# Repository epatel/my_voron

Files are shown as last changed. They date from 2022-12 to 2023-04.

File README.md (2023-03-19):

# My Vorons

## Voron 2.4r2

```
Size: 300x300
Hotend: E3D Revo
```

### Serial

[https://www.reddit.com/r/voroncorexy/comments/z64f42/serial_request_voron_24r2_300_epatel6397/](https://www.reddit.com/r/voroncorexy/comments/z64f42/serial_request_voron_24r2_300_epatel6397/)

## Voron 0.1

```
Size: 120x120
Hotend: E3D Revo
```

### Serial

[https://www.reddit.com/r/voroncorexy/comments/11r398s/serial_request_voron_01_epatel6397/](https://www.reddit.com/r/voroncorexy/comments/11r398s/serial_request_voron_01_epatel6397/)

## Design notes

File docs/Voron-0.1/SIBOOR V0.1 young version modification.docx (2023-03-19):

printer.cfg：

# BED

[heater_bed]

heater_pin: BED_OUT

sensor_pin: BED_TEMP

sensor_type: ATC Semitec 104GT-2

control: watermark

min_temp: 0

max_temp: 100 ##Limit the maximum temperature. If the set value is exceeded, an error will be reported and the operation will be stopped

max_power: 0.5 ##Limited heating power, 0. x represents percentage, 0.5 represents 50% power

The original FLY version is set to the maximum temperature of 200 degrees. The young version hot bed is heated faster, which may cause danger if the heating is too high. Now the maximum temperature is 100 degrees, and the heating power is 50%

[tmc2209 stepper_x]

uart_pin: X_CS

run_current: 0.800

interpolate: False

stealthchop_threshold:200 #Mute threshold to reduce motor running noise, recommended between 100-200

[tmc2209 stepper_y]

uart_pin: Y_CS

run_current: 0.800

interpolate: False

stealthchop_threshold:200 #Mute threshold to reduce motor running noise, recommended between 100-200

[tmc2209 stepper_z]

uart_pin: Z_CS

run_current: 0.4500 #The operating current of Axis Z is changed from 0.8 to 0.45. High current is not required for Axis Z to avoid serious heating

interpolate: False

[tmc2209 extruder]

uart_pin: E_CS

run_current: 0.4500 #The youth version is an ordinary motor. The current is changed from 0.8 to 0.45 to avoid serious heating

interpolate: False

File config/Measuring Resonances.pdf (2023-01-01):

# Measuring Resonances

Klipper has built-in support for ADXL345 accelerometer, which can be used to measure resonance frequencies of the printer for different axes, and auto-tune input shapers (https://www.klipper3d.org/Resonance_Compensation.html) to compensate for resonances. Note that using ADXL345 requires some soldering and crimping. ADXL345 can be connected to a Raspberry Pi directly, or to an SPI interface of an MCU board (it needs to be reasonably fast).

When sourcing ADXL345, be aware that there is a variety of different PCB board designs and different clones of them. Make sure that the board supports SPI mode (small number of boards appear to be hard-configured for I2C by pulling SDO to GND), and, if it is going to be connected to a 5V printer MCU, that it has a voltage regulator and a level shifter.

## Installation instructions

### Wiring

An ethernet cable with shielded twisted pairs (cat5e or better) is recommended for signal integrety over a long distance. If you still experience signal integrity issues (SPI/I2C errors), shorten the cable.

Connect ethernet cable shielding to the controller board/RPI ground.

Double-check your wiring before powering up to prevent damaging your MCU/Raspberry Pi or the accelerometer.

SPI Accelerometers

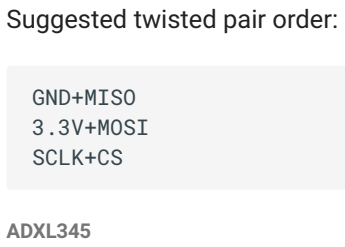
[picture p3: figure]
Suggested twisted pair order:; ADXL345; GND+MISO 3.3V+MOSI SCLK+CS

Note: Many MCUs will work with an ADXL345 in SPI mode(eg Pi Pico), wiring and configuration will vary according to your specific board and avaliable pins.

You need to connect ADXL345 to your Raspberry Pi via SPI. Note that the I2C connection, which is suggested by ADXL345 documentation, has too low throughput and will not work. The recommended connection scheme:

ADXL345 pin | RPi pin | RPi pin name
3V3 (or VCC) | 01 | 3.3v DC power
GND | 06 | Ground
CS | 24 | GPIO08 (SPI0_CE0_N)
SDO | 21 | GPIO09 (SPI0_MISO)
SDA | 19 | GPIO10 (SPI0_MOSI)
SCL | 23 | GPIO11 (SPI0_SCLK)

Fritzing wiring diagrams for some of the ADXL345 boards:

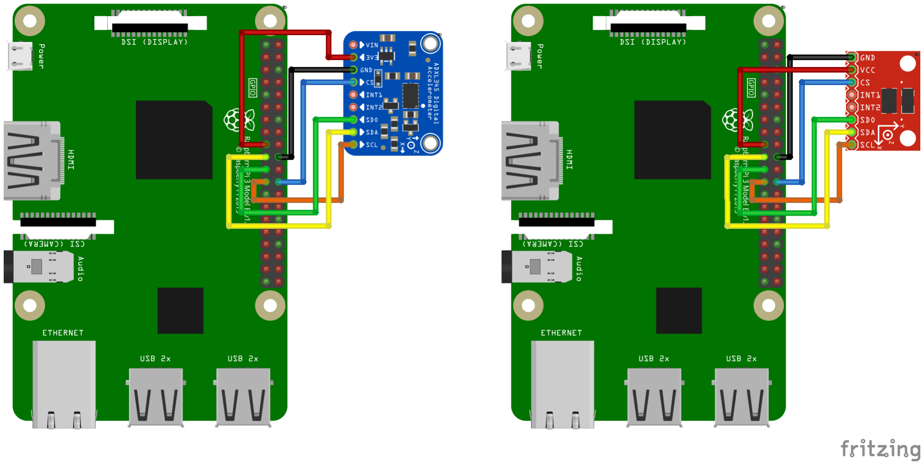
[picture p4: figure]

I2C Accelerometers

Suggested twisted pair order:

MPU-9250/MPU-9255/MPU-6515/MPU-6050/MPU-6500

Alternatives to the ADXL345 are MPU-9250/MPU-9255/MPU-6515/MPU-6050/MPU-6500. These accelerometers have been tested to work over I2C on the RPi or RP2040(pico) at 400kbaud.

3.3V+SDA
GND+SCL

Recommended connection scheme for I2C on the Raspberry Pi:

MPU-9250 pin | RPi pin | RPi pin name
VCC | 01 | 3.3v DC power
GND | 09 | Ground
SDA | 03 | GPIO02 (SDA1)
SCL | 05 | GPIO03 (SCL1)

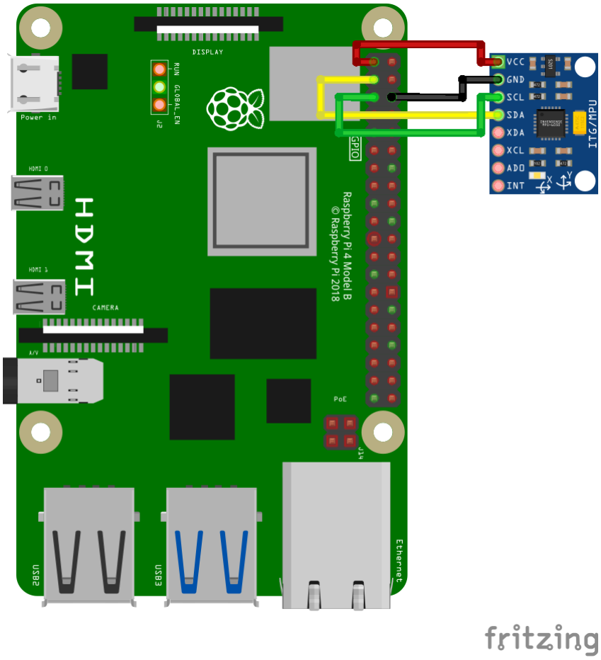
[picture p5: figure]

Recommended connection scheme for I2C(i2c0a) on the RP2040:

MPU-9250 pin | RP2040 pin | RPi pin name
VCC | 39 | 3v3
GND | 38 | Ground
SDA | 01 | GP0 (I2C0 SDA)
SCL | 02 | GP1 (I2C0 SCL)

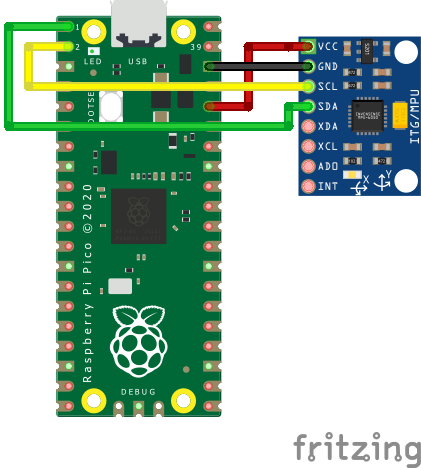
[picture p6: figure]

### Mounting the accelerometer

The accelerometer must be attached to the toolhead. One needs to design a proper mount that fits their own 3D printer. It is better to align the axes of the accelerometer with the printer's axes (but if it makes it more convenient, axes can be swapped - i.e. no need to align X axis with X and so forth - it should be fine even if Z axis of accelerometer is X axis of the printer, etc.).

An example of mounting ADXL345 on the SmartEffector:

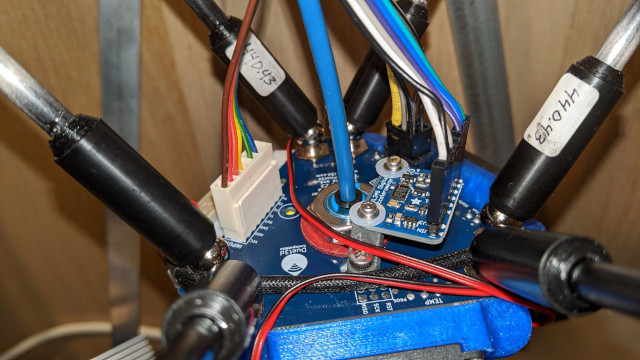
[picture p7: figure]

Note that on a bed slinger printer one must design 2 mounts: one for the toolhead and one for the bed, and run the measurements twice. See the corresponding section for more details.

Attention: make sure the accelerometer and any screws that hold it in place do not touch any metal parts of the printer. Basically, the mount must be designed such as to ensure the electrical isolation of the accelerometer from the printer frame. Failing to ensure that can create a ground loop in the system that may damage the electronics.

### Software installation

Note that resonance measurements and shaper auto-calibration require additional software dependencies not installed by default. First, run on your Raspberry Pi the following commands:

Next, in order to install NumPy in the Klipper environment, run the command:

Note that, depending on the performance of the CPU, it may take a lot of time, up to 10-20 minutes. Be patient and wait for the completion of the installation. On some occasions, if the board has too little RAM the installation may fail and you will need to enable swap.

Afterwards, check and follow the instructions in the RPi Microcontroller document (https://www.klipper3d.org/RPi_microcontroller.html) to setup the "linux mcu" on the Raspberry Pi.

sudo apt update
sudo apt install python3-numpy python3-matplotlib libatlas-base-dev

~/klippy-env/bin/pip install -v numpy

Configure ADXL345 With RPi

Make sure the Linux SPI driver is enabled by running sudo raspi-config and enabling SPI under the "Interfacing options" menu.

Add the following to the printer.cfg file:

It is advised to start with 1 probe point, in the middle of the print bed, slightly above it.

Configure MPU-6000/9000 series With RPi

Make sure the Linux I2C driver is enabled and the baud rate is set to 400000 (see Enabling I2C (https://www.klipper3d.org/RPi_microcontroller.html#optional-enabling-i2c) section for more details). Then, add the following to the printer.cfg:

Configure MPU-6000/9000 series With PICO

PICO I2C is set to 400000 on default. Simply add the following to the printer.cfg:

[mcu rpi]
serial: /tmp/klipper_host_mcu

[adxl345]
cs_pin: rpi:None

[resonance_tester]
accel_chip: adxl345
probe_points:
100, 100, 20 # an example

[mcu rpi]
serial: /tmp/klipper_host_mcu

[mpu9250]
i2c_mcu: rpi
i2c_bus: i2c.1

[resonance_tester]
accel_chip: mpu9250
probe_points:
100, 100, 20 # an example

[mcu pico]
serial: /dev/serial/by-id/<your PICO's serial ID>

[mpu9250]
i2c_mcu: pico
i2c_bus: i2c1a

[resonance_tester]
accel_chip: mpu9250
probe_points:
100, 100, 20 # an example

Restart Klipper via the RESTART command.

## Measuring the resonances

### Checking the setup

Now you can test a connection.

For "non bed-slingers" (e.g. one accelerometer), in Octoprint, enter ACCELEROMETER_QUERY

For "bed-slingers" (e.g. more than one accelerometer), enter ACCELEROMETER_QUERY CHIP= <chip> where <chip> is the name of the chip as-entered, e.g. CHIP=bed (see: bed-slinger) for all installed accelerometer chips.

You should see the current measurements from the accelerometer, including the free-fall

If you get an error like Invalid adxl345 id (got xx vs e5) , where xx is some other ID, it is indicative of the connection problem with ADXL345, or the faulty sensor. Double-check the power, the wiring (that it matches the schematics, no wire is broken or loose, etc.), and soldering quality.

If you are using MPU-6000/9000 series accelerometer and it show up as mpu-unknown , use with caution! They are probably refurbished chips!

Next, try running MEASURE_AXES_NOISE in Octoprint, you should get some baseline numbers for the noise of accelerometer on the axes (should be somewhere in the range of ~1-100). Too high axes noise (e.g. 1000 and more) can be indicative of the sensor issues, problems with its power, or too noisy imbalanced fans on a 3D printer.

### Measuring the resonances

Now you can run some real-life tests. Run the following command:

Note that it will create vibrations on X axis. It will also disable input shaping if it was enabled previously, as it is not valid to run the resonance testing with the input shaper enabled.

[static_digital_output pico_3V3pwm] # Improve power stability

Recv: // adxl345 values (x, y, z): 470.719200, 941.438400, 9728.196800

TEST_RESONANCES AXIS=X

Attention! Be sure to observe the printer for the first time, to make sure the vibrations do not become too violent ( M112 command can be used to abort the test in case of emergency; hopefully it will not come to this though). If the vibrations do get too strong, you can attempt to specify a lower than the default value for accel_per_hz parameter in [resonance_tester]

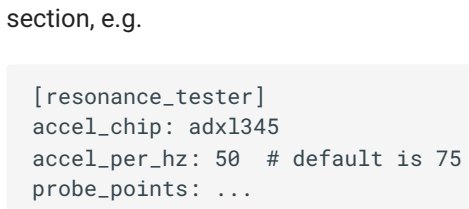
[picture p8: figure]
section, e.g.; [resonance_tester] accel_chip: adxl345 accel_per_hz: 50 # default is 75 probe_points: ...

If it works for X axis, run for Y axis as well:

This will generate 2 CSV files ( /tmp/resonances_x_*.csv and /tmp/resonances_y_*.csv ). These files can be processed with the stand-alone script on a Raspberry Pi. To do that, run the

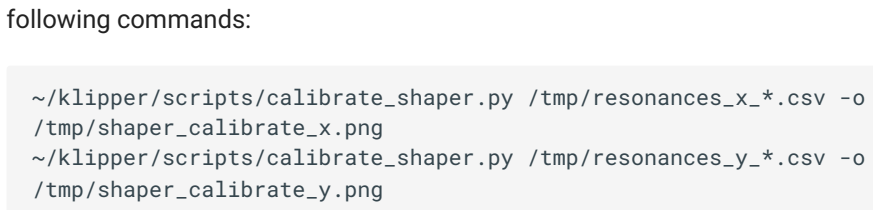
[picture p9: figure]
following commands:; ~/klipper/scripts/calibrate_shaper.py /tmp/resonances_x_*.csv -o /tmp/shaper_calibrate_x.png ~/klipper/scripts/calibrate_shaper.py /tmp/resonances_y_*.csv -o /tmp/shaper_calibrate_y.png

This script will generate the charts /tmp/shaper_calibrate_x.png and /tmp/shaper_calibrate_y.png with frequency responses. You will also get the suggested frequencies for each input shaper, as well as which input shaper is recommended for your setup. For example:

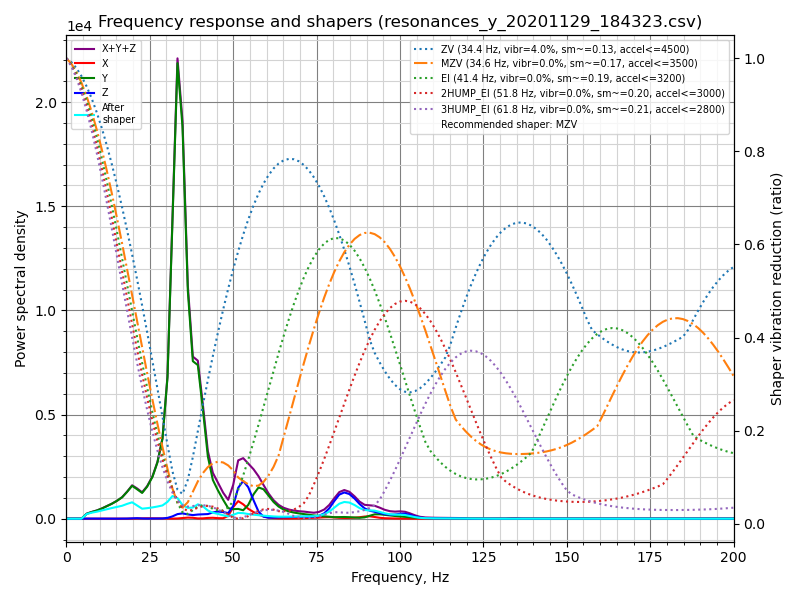
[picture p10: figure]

The suggested configuration can be added to [input_shaper] section of printer.cfg , e.g.:

Fitted shaper 'zv' frequency = 34.4 Hz (vibrations = 4.0%, smoothing ~= 0.132) To avoid too much smoothing with 'zv', suggested max_accel <= 4500 mm/sec^2 Fitted shaper 'mzv' frequency = 34.6 Hz (vibrations = 0.0%, smoothing ~= 0.170)
To avoid too much smoothing with 'mzv', suggested max_accel <= 3500 mm/sec^2 Fitted shaper 'ei' frequency = 41.4 Hz (vibrations = 0.0%, smoothing ~= 0.188) To avoid too much smoothing with 'ei', suggested max_accel <= 3200 mm/sec^2 Fitted shaper '2hump_ei' frequency = 51.8 Hz (vibrations = 0.0%, smoothing ~= 0.201)
To avoid too much smoothing with '2hump_ei', suggested max_accel <= 3000 mm/sec^2
Fitted shaper '3hump_ei' frequency = 61.8 Hz (vibrations = 0.0%, smoothing ~= 0.215)
To avoid too much smoothing with '3hump_ei', suggested max_accel <= 2800 mm/sec^2
Recommended shaper is mzv @ 34.6 Hz

[input_shaper]
shaper_freq_x: ...
shaper_type_x: ...
shaper_freq_y: 34.6
shaper_type_y: mzv

[printer]
max_accel: 3000 # should not exceed the estimated max_accel for X and Y axes

or you can choose some other configuration yourself based on the generated charts: peaks in the power spectral density on the charts correspond to the resonance frequencies of the printer.

Note that alternatively you can run the input shaper autocalibration from Klipper directly, which can be convenient, for example, for the input shaper re-calibration.

### Bed-slinger printers

If your printer is a bed slinger printer, you will need to change the location of the accelerometer between the measurements for X and Y axes: measure the resonances of X axis with the accelerometer attached to the toolhead and the resonances of Y axis - to the bed (the usual bed slinger setup).

However, you can also connect two accelerometers simultaneously, though they must be connected to different boards (say, to an RPi and printer MCU board), or to two different physical SPI interfaces on the same board (rarely available). Then they can be configured in the following manner:

Then the commands TEST_RESONANCES AXIS=X and TEST_RESONANCES AXIS=Y will use the correct accelerometer for each axis.

### Max smoothing

Keep in mind that the input shaper can create some smoothing in parts. Automatic tuning of the input shaper performed by calibrate_shaper.py script or SHAPER_CALIBRATE command tries not to exacerbate the smoothing, but at the same time they try to minimize the resulting vibrations. Sometimes they can make a sub-optimal choice of the shaper frequency, or maybe you simply prefer to have less smoothing in parts at the expense of a larger remaining vibrations. In these cases, you can request to limit the maximum smoothing from the input shaper.

Let's consider the following results from the automatic tuning:

[adxl345 hotend]
# Assuming `hotend` chip is connected to an RPi

cs_pin: rpi:None

[adxl345 bed]
# Assuming `bed` chip is connected to a printer MCU board cs_pin: ... # Printer board SPI chip select (CS) pin

[resonance_tester]
# Assuming the typical setup of the bed slinger printer accel_chip_x: adxl345 hotend

accel_chip_y: adxl345 bed
probe_points: ...

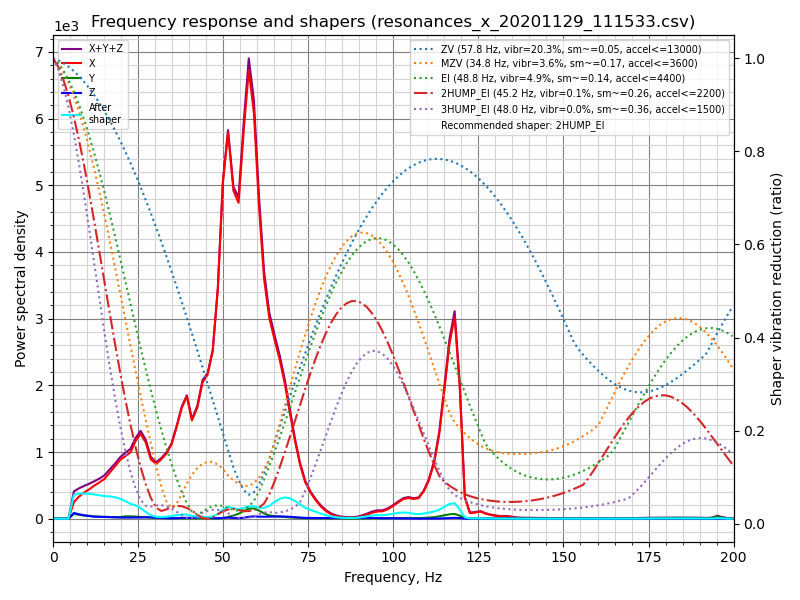
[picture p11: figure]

Note that the reported smoothing values are some abstract projected values. These values can be used to compare different configurations: the higher the value, the more smoothing a shaper will create. However, these smoothing scores do not represent any real measure of smoothing, because the actual smoothing depends on max_accel and square_corner_velocity parameters. Therefore, you should print some test prints to see how much smoothing exactly a chosen configuration creates.

Fitted shaper 'zv' frequency = 57.8 Hz (vibrations = 20.3%, smoothing ~= 0.053)
To avoid too much smoothing with 'zv', suggested max_accel <= 13000 mm/sec^2 Fitted shaper 'mzv' frequency = 34.8 Hz (vibrations = 3.6%, smoothing ~= 0.168)
To avoid too much smoothing with 'mzv', suggested max_accel <= 3600 mm/sec^2 Fitted shaper 'ei' frequency = 48.8 Hz (vibrations = 4.9%, smoothing ~= 0.135) To avoid too much smoothing with 'ei', suggested max_accel <= 4400 mm/sec^2 Fitted shaper '2hump_ei' frequency = 45.2 Hz (vibrations = 0.1%, smoothing ~= 0.264)
To avoid too much smoothing with '2hump_ei', suggested max_accel <= 2200 mm/sec^2
Fitted shaper '3hump_ei' frequency = 48.0 Hz (vibrations = 0.0%, smoothing ~= 0.356)
To avoid too much smoothing with '3hump_ei', suggested max_accel <= 1500 mm/sec^2
Recommended shaper is 2hump_ei @ 45.2 Hz

In the example above the suggested shaper parameters are not bad, but what if you want to get less smoothing on the X axis? You can try to limit the maximum shaper smoothing using the following command:

which limits the smoothing to 0.2 score. Now you can get the following result:

~/klipper/scripts/calibrate_shaper.py /tmp/resonances_x_*.csv -o /tmp/shaper_calibrate_x.png --max_smoothing=0.2

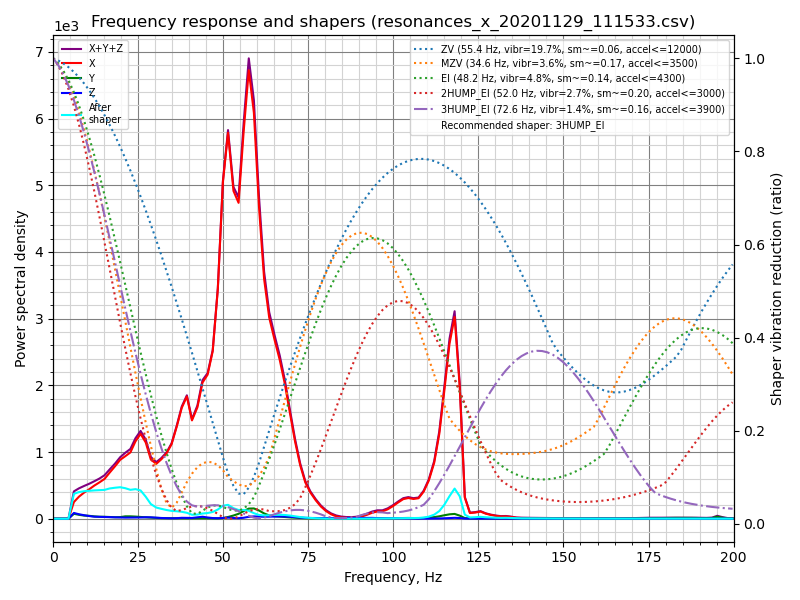
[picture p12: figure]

Fitted shaper 'zv' frequency = 55.4 Hz (vibrations = 19.7%, smoothing ~= 0.057)
To avoid too much smoothing with 'zv', suggested max_accel <= 12000 mm/sec^2 Fitted shaper 'mzv' frequency = 34.6 Hz (vibrations = 3.6%, smoothing ~= 0.170)
To avoid too much smoothing with 'mzv', suggested max_accel <= 3500 mm/sec^2 Fitted shaper 'ei' frequency = 48.2 Hz (vibrations = 4.8%, smoothing ~= 0.139) To avoid too much smoothing with 'ei', suggested max_accel <= 4300 mm/sec^2 Fitted shaper '2hump_ei' frequency = 52.0 Hz (vibrations = 2.7%, smoothing ~= 0.200)
To avoid too much smoothing with '2hump_ei', suggested max_accel <= 3000 mm/sec^2
Fitted shaper '3hump_ei' frequency = 72.6 Hz (vibrations = 1.4%, smoothing ~= 0.155)
To avoid too much smoothing with '3hump_ei', suggested max_accel <= 3900 mm/sec^2
Recommended shaper is 3hump_ei @ 72.6 Hz

If you compare to the previously suggested parameters, the vibrations are a bit larger, but the smoothing is significantly smaller than previously, allowing larger maximum acceleration.

When deciding which max_smoothing parameter to choose, you can use a trial-and-error approach. Try a few different values and see which results you get. Note that the actual smoothing produced by the input shaper depends, primarily, on the lowest resonance frequency of the printer: the higher the frequency of the lowest resonance - the smaller the smoothing. Therefore, if you request the script to find a configuration of the input shaper with the unrealistically small smoothing, it will be at the expense of increased ringing at the lowest resonance frequencies (which are, typically, also more prominently visible in prints). So, always double-check the projected remaining vibrations reported by the script and make sure they are not too high.

Note that if you chose a good max_smoothing value for both of your axes, you can store it in

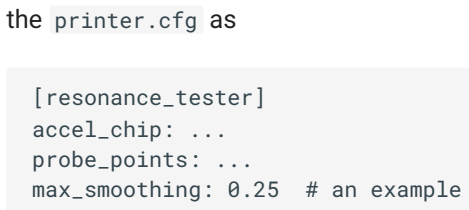
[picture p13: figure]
the printer.cfg as; [resonance_tester] accel_chip: ... probe_points: ... max_smoothing: 0.25 # an example

Then, if you rerun the input shaper auto-tuning using SHAPER_CALIBRATE Klipper command in the future, it will use the stored max_smoothing value as a reference.

### Selecting max_accel

Since the input shaper can create some smoothing in parts, especially at high accelerations, you will still need to choose the max_accel value that does not create too much smoothing in the printed parts. A calibration script provides an estimate for max_accel parameter that should not create too much smoothing. Note that the max_accel as displayed by the calibration script is only a theoretical maximum at which the respective shaper is still able to work without producing too much smoothing. It is by no means a recommendation to set this acceleration for printing. The maximum acceleration your printer is able to sustain depends on its mechanical properties and the maximum torque of the used stepper motors. Therefore, it is suggested to set max_accel in [printer] section that does not exceed the estimated values for X and Y axes, likely with some conservative safety margin.

Alternatively, follow this (https://www.klipper3d.org/Resonance_Compensation.html#selecting-max_accel) part of the input shaper tuning guide and print the test model to choose max_accel parameter experimentally.

The same notice applies to the input shaper auto-calibration with SHAPER_CALIBRATE command: it is still necessary to choose the right max_accel value after the auto-calibration, and the suggested acceleration limits will not be applied automatically.

If you are doing a shaper re-calibration and the reported smoothing for the suggested shaper configuration is almost the same as what you got during the previous calibration, this step can be skipped.

### Testing custom axes

TEST_RESONANCES command supports custom axes. While this is not really useful for input shaper calibration, it can be used to study printer resonances in-depth and to check, for example, belt tension.

To check the belt tension on CoreXY printers, execute

and use graph_accelerometer.py to process the generated files, e.g.

which will generate /tmp/resonances.png comparing the resonances.

For Delta printers with the default tower placement (tower A ~= 210 degrees, B ~= 330 degrees, and C ~= 90 degrees), execute

and then use the same command

to generate /tmp/resonances.png comparing the resonances.

## Input Shaper auto-calibration

Besides manually choosing the appropriate parameters for the input shaper feature, it is also possible to run the auto-tuning for the input shaper directly from Klipper. Run the following command via Octoprint terminal:

TEST_RESONANCES AXIS=1,1 OUTPUT=raw_data TEST_RESONANCES AXIS=1,-1 OUTPUT=raw_data

~/klipper/scripts/graph_accelerometer.py -c /tmp/raw_data_axis*.csv -o /tmp/resonances.png

SHAPER_CALIBRATE

This will run the full test for both axes and generate the csv output
( /tmp/calibration_data_*.csv by default) for the frequency response and the suggested input shapers. You will also get the suggested frequencies for each input shaper, as well as which input shaper is recommended for your setup, on Octoprint console. For example:

If you agree with the suggested parameters, you can execute SAVE_CONFIG now to save them and restart the Klipper. Note that this will not update max_accel value in [printer] section. You should update it manually following the considerations in Selecting max_accel section.

If your printer is a bed slinger printer, you can specify which axis to test, so that you can change the accelerometer mounting point between the tests (by default the test is performed for both

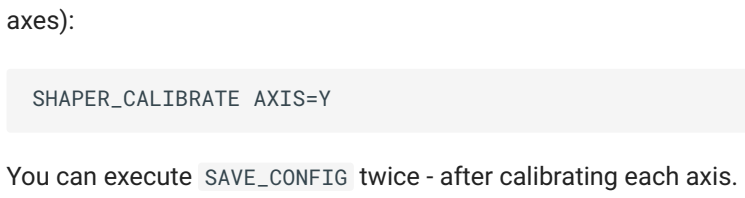
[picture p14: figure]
axes):; SHAPER_CALIBRATE AXIS=Y

You can execute SAVE_CONFIG twice - after calibrating each axis.

However, if you connected two accelerometers simultaneously, you simply run SHAPER_CALIBRATE without specifying an axis to calibrate the input shaper for both axes in one go.

### Input Shaper re-calibration

SHAPER_CALIBRATE command can be also used to re-calibrate the input shaper in the future, especially if some changes to the printer that can affect its kinematics are made. One can either re-run the full calibration using SHAPER_CALIBRATE command, or restrict the autocalibration to a single axis by supplying AXIS= parameter, like

Calculating the best input shaper parameters for y axis
Fitted shaper 'zv' frequency = 39.0 Hz (vibrations = 13.2%, smoothing ~= 0.105)
To avoid too much smoothing with 'zv', suggested max_accel <= 5900 mm/sec^2 Fitted shaper 'mzv' frequency = 36.8 Hz (vibrations = 1.7%, smoothing ~= 0.150)
To avoid too much smoothing with 'mzv', suggested max_accel <= 4000 mm/sec^2 Fitted shaper 'ei' frequency = 36.6 Hz (vibrations = 2.2%, smoothing ~= 0.240) To avoid too much smoothing with 'ei', suggested max_accel <= 2500 mm/sec^2 Fitted shaper '2hump_ei' frequency = 48.0 Hz (vibrations = 0.0%, smoothing ~= 0.234)
To avoid too much smoothing with '2hump_ei', suggested max_accel <= 2500 mm/sec^2
Fitted shaper '3hump_ei' frequency = 59.0 Hz (vibrations = 0.0%, smoothing ~= 0.235)
To avoid too much smoothing with '3hump_ei', suggested max_accel <= 2500 mm/sec^2
Recommended shaper_type_y = mzv, shaper_freq_y = 36.8 Hz

SHAPER_CALIBRATE AXIS=X

Warning! It is not advisable to run the shaper autocalibration very frequently (e.g. before every print, or every day). In order to determine resonance frequencies, autocalibration creates intensive vibrations on each of the axes. Generally, 3D printers are not designed to withstand a prolonged exposure to vibrations near the resonance frequencies. Doing so may increase wear of the printer components and reduce their lifespan. There is also an increased risk of some parts unscrewing or becoming loose. Always check that all parts of the printer (including the ones that may normally not move) are securely fixed in place after each auto-tuning.

Also, due to some noise in measurements, it is possible that the tuning results will be slightly different from one calibration run to another one. Still, it is not expected that the noise will affect the print quality too much. However, it is still advised to double-check the suggested parameters, and print some test prints before using them to confirm they are good.

## Offline processing of the accelerometer data

It is possible to generate the raw accelerometer data and process it offline (e.g. on a host machine), for example to find resonances. In order to do so, run the following commands via Octoprint terminal:

ignoring any errors for SET_INPUT_SHAPER command. For TEST_RESONANCES command, specify the desired test axis. The raw data will be written into /tmp directory on the RPi.

The raw data can also be obtained by running the command ACCELEROMETER_MEASURE command twice during some normal printer activity - first to start the measurements, and then to stop them and write the output file. Refer to G-Codes (https://www.klipper3d.org/G-Codes.html#adxl345) for more details.

The data can be processed later by the following scripts: scripts/graph_accelerometer.py and scripts/calibrate_shaper.py . Both of them accept one or several raw csv files as the input depending on the mode. The graph_accelerometer.py script supports several modes of operation:

plotting raw accelerometer data (use -r parameter), only 1 input is supported;

plotting a frequency response (no extra parameters required), if multiple inputs are specified, the average frequency response is computed;

comparison of the frequency response between several inputs (use -c parameter); you can additionally specify which accelerometer axis to consider via -a x , -a y or -a z parameter (if none specified, the sum of vibrations for all axes is used);

plotting the spectrogram (use -s parameter), only 1 input is supported; you can additionally specify which accelerometer axis to consider via -a x , -a y or -a z parameter (if none specified, the sum of vibrations for all axes is used).

SET_INPUT_SHAPER SHAPER_FREQ_X=0 SHAPER_FREQ_Y=0 TEST_RESONANCES AXIS=X OUTPUT=raw_data

Note that graph_accelerometer.py script supports only the raw_data*.csv files and not resonances*.csv or calibration_data*.csv files.

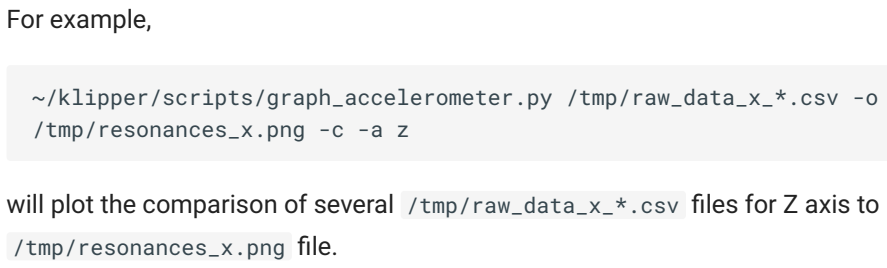
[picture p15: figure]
For example,; /tmp/resonances_x.png file.; ~/klipper/scripts/graph_accelerometer.py /tmp/raw_data_x_*.csv -o /tmp/resonances_x.png -c -a z

will plot the comparison of several /tmp/raw_data_x_*.csv files for Z axis to

The shaper_calibrate.py script accepts 1 or several inputs and can run automatic tuning of the input shaper and suggest the best parameters that work well for all provided inputs. It prints the suggested parameters to the console, and can additionally generate the chart if -o output.png parameter is provided, or the CSV file if -c output.csv parameter is specified.

Providing several inputs to shaper_calibrate.py script can be useful if running some advanced tuning of the input shapers, for example:

Running TEST_RESONANCES AXIS=X OUTPUT=raw_data (and Y axis) for a single axis twice on a bed slinger printer with the accelerometer attached to the toolhead the first time, and the accelerometer attached to the bed the second time in order to detect axes cross-resonances and attempt to cancel them with input shapers.

Running TEST_RESONANCES AXIS=Y OUTPUT=raw_data twice on a bed slinger with a glass bed and a magnetic surfaces (which is lighter) to find the input shaper parameters that work well for any print surface configuration.

Combining the resonance data from multiple test points.

Combining the resonance data from 2 axis (e.g. on a bed slinger printer to configure X-axis input_shaper from both X and Y axes resonances to cancel vibrations of the bed in case the nozzle 'catches' a print when moving in X axis direction).

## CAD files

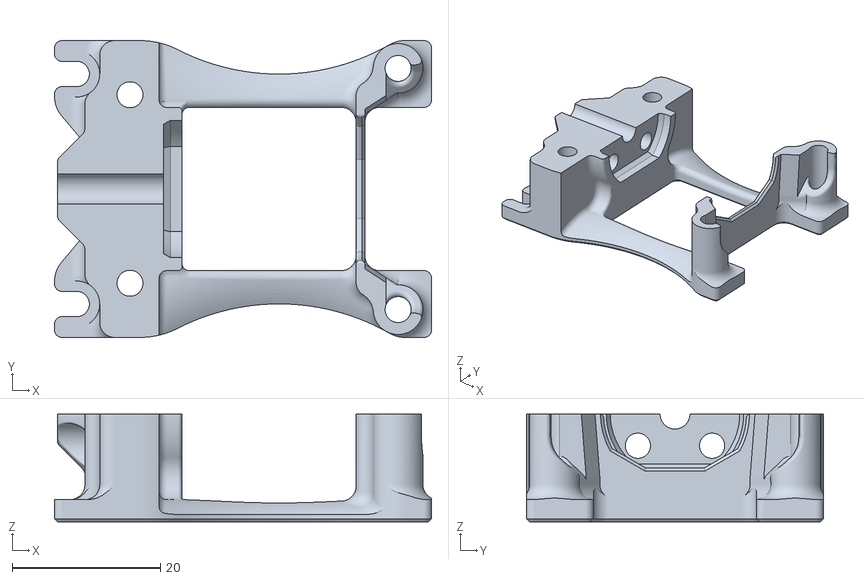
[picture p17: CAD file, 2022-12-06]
models/Revo_Afterburner/printhead_rear_revovoron.stl
50.8 x 40.0 x 14.5

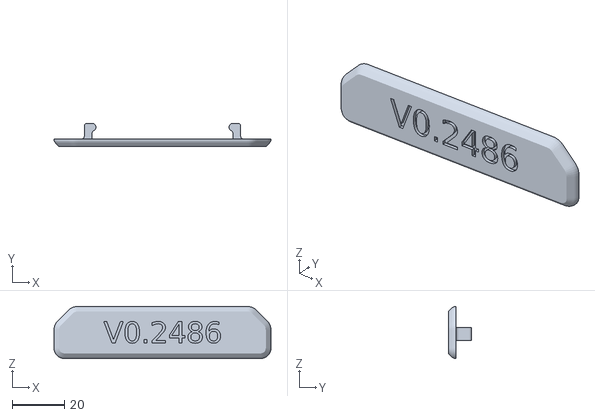
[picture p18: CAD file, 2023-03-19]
models/V0.2486-NoLogo.stl
83.2 x 9.00 x 20.0

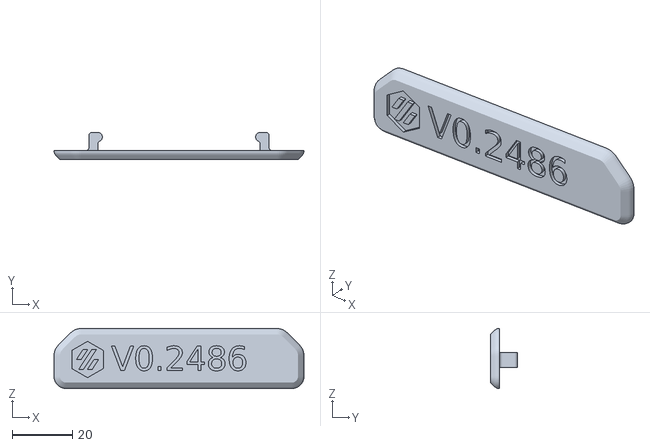
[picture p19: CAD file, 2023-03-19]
models/V0.2486.stl
83.2 x 9.00 x 20.0

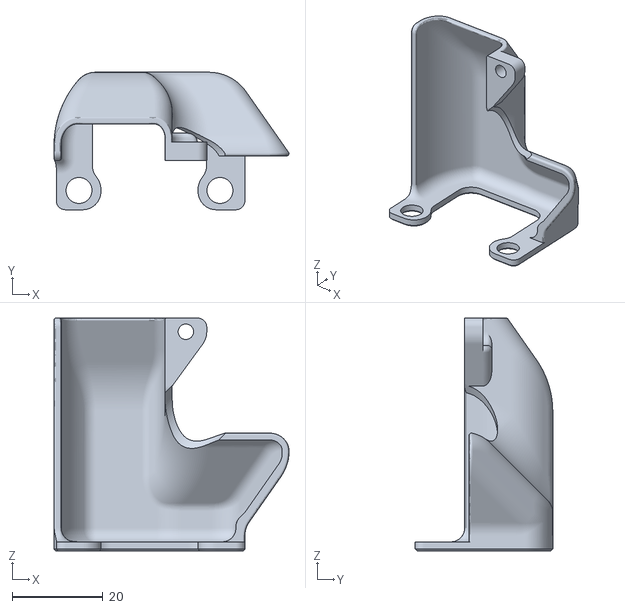
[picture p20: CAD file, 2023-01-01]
models/ab-cover-cutout.stl
51.7 x 30.3 x 51.2

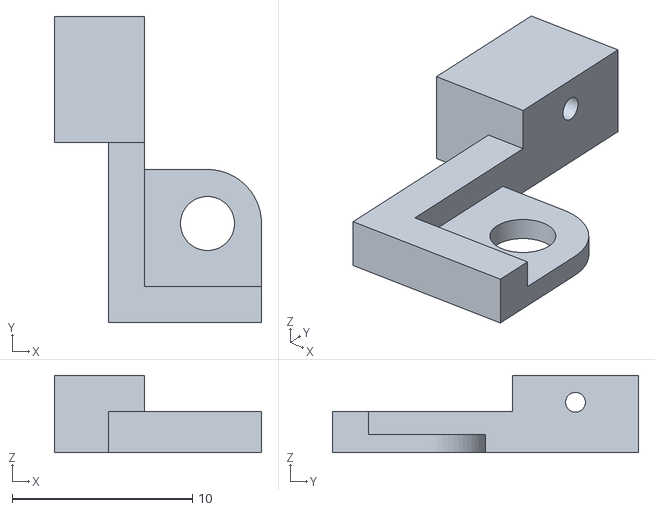
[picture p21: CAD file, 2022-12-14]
models/fiber-rpi4.stl
11.5 x 17.0 x 4.30

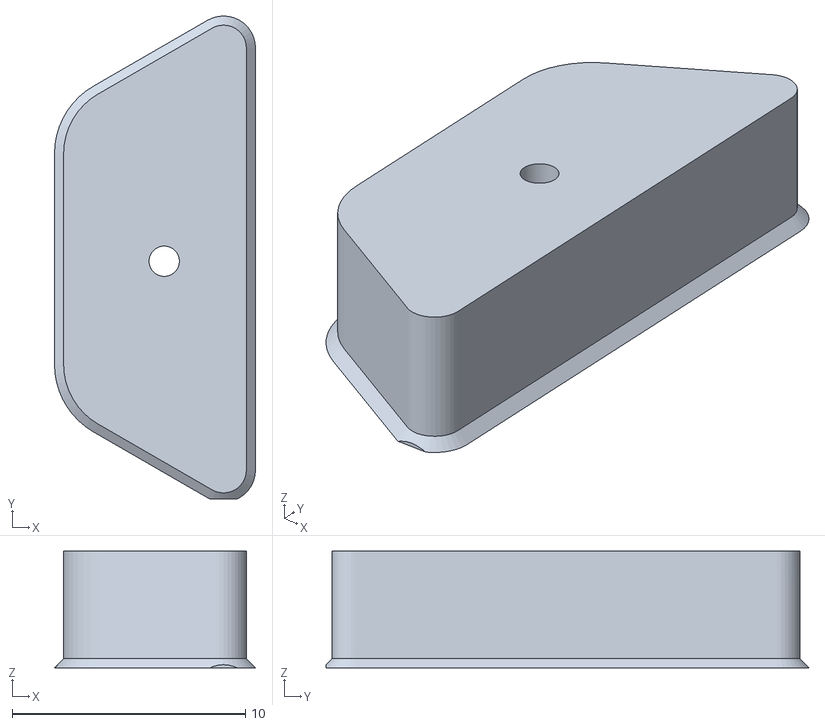
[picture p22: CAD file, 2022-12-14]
models/fiber-skirt.stl
8.62 x 20.7 x 5.00

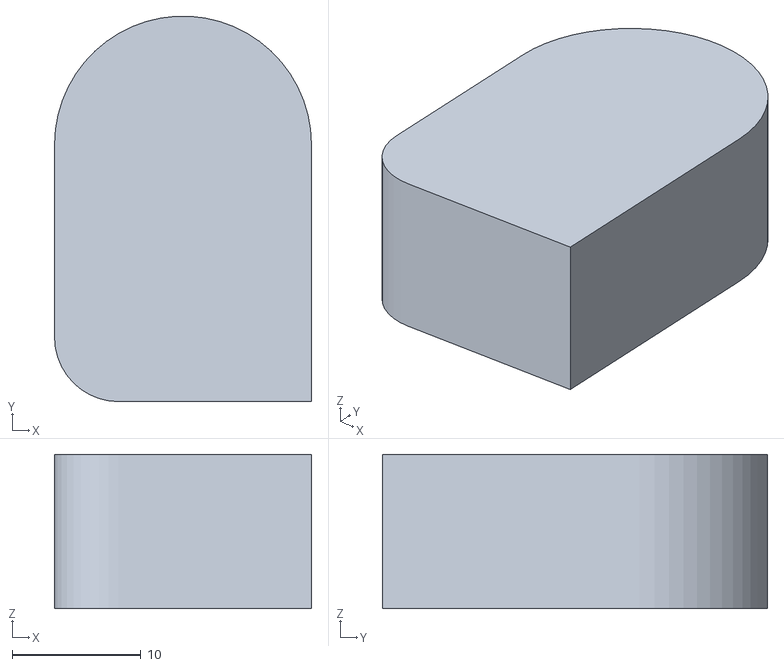
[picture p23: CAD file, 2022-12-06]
models/40x10-solid.stl
20.0 x 30.0 x 12.0

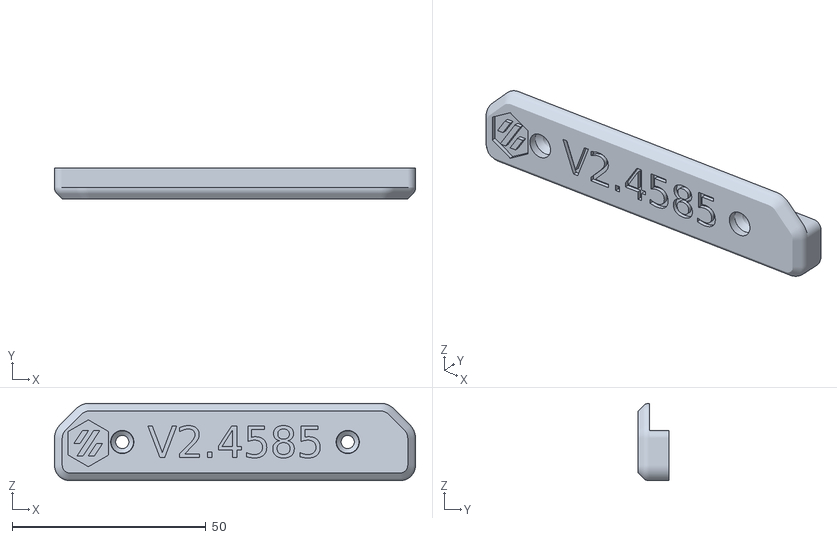
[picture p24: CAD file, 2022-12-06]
models/V2.4585.stl
93.2 x 8.00 x 20.0

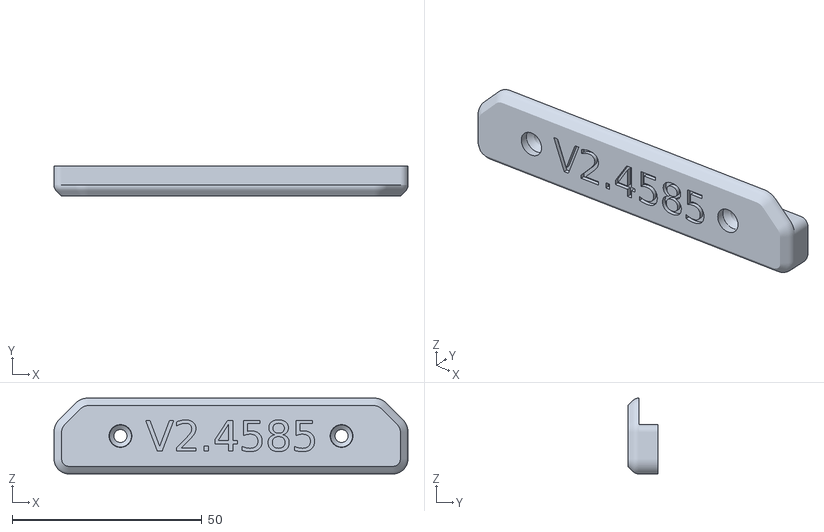
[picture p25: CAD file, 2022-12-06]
models/V2.4585-NoLogo.stl
93.2 x 8.00 x 20.0

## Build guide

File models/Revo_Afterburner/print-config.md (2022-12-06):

Print Settings
These are the recommended settings.

Layer height:             0.2mm
Extrusion width:          0.4mm, forced
Infill pecentage:         40%
Infill type:              grid, gyroid, honeycomb, triangle, or cubic
Wall count:               4
Solid top/bottom layers:  5
Supports:                 NONE

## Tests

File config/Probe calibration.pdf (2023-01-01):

# Probe calibration

This document describes the method for calibrating the X, Y, and Z offsets of an "automatic z probe" in Klipper. This is useful for users that have a [probe] or [bltouch] section in their config file.

## Calibrating probe X and Y offsets

To calibrate the X and Y offset, navigate to the OctoPrint "Control" tab, home the printer, and then use the OctoPrint jogging buttons to move the head to a position near the center of the bed.

Place a piece of blue painters tape (or similar) on the bed underneath the probe. Navigate to the OctoPrint "Terminal" tab and issue a PROBE command:

Place a mark on the tape directly under where the probe is (or use a similar method to note the location on the bed).

Issue a GET_POSITION command and record the toolhead XY location reported by that command. For example if one sees:

then one would record a probe X position of 46.5 and probe Y position of 27.

After recording the probe position, issue a series of G1 commands until the nozzle is directly above the mark on the bed. For example, one might issue:

to move the nozzle to an X position of 57 and Y of 30. Once one finds the position directly above the mark, use the GET_POSITION command to report that position. This is the nozzle position.

The x_offset is then the nozzle_x_position - probe_x_position and y_offset is similarly the nozzle_y_position - probe_y_position . Update the printer.cfg file with the given values, remove the tape/marks from the bed, and then issue a RESTART command so that the new values take effect.

PROBE

Recv: // toolhead: X:46.500000 Y:27.000000 Z:15.000000 E:0.000000

G1 F300 X57 Y30 Z15

## Calibrating probe Z offset

Providing an accurate probe z_offset is critical to obtaining high quality prints. The z_offset is the distance between the nozzle and bed when the probe triggers. The Klipper PROBE_CALIBRATE tool can be used to obtain this value - it will run an automatic probe to measure the probe's Z trigger position and then start a manual probe to obtain the nozzle Z height. The probe z_offset will then be calculated from these measurements.

Start by homing the printer and then move the head to a position near the center of the bed. Navigate to the OctoPrint terminal tab and run the PROBE_CALIBRATE command to start the tool.

This tool will perform an automatic probe, then lift the head, move the nozzle over the location of the probe point, and start the manual probe tool. If the nozzle does not move to a position above the automatic probe point, then ABORT the manual probe tool and perform the XY probe offset calibration described above.

Once the manual probe tool starts, follow the steps described at "the paper test") (https://www.klipper3d.org/Bed_Level.html#the-paper-test) to determine the actual distance between the nozzle and bed at the given location. Once those steps are

complete one can ACCEPT the position and save the results to the config file with:

Note that if a change is made to the printer's motion system, hotend position, or probe location then it will invalidate the results of PROBE_CALIBRATE.

If the probe has an X or Y offset and the bed tilt is changed (eg, by adjusting bed screws, running DELTA_CALIBRATE, running Z_TILT_ADJUST, running QUAD_GANTRY_LEVEL, or similar) then it will invalidate the results of PROBE_CALIBRATE. After making any of the above adjustments it will be necessary to run PROBE_CALIBRATE again.

If the results of PROBE_CALIBRATE are invalidated, then any previous bed mesh (https://www.klipper3d.org/Bed_Mesh.html) results that were obtained using the probe are also invalidated - it will be necessary to rerun BED_MESH_CALIBRATE after recalibrating the probe.

## Repeatability check

After calibrating the probe X, Y, and Z offsets it is a good idea to verify that the probe provides repeatable results. Start by homing the printer and then move the head to a position near the center of the bed. Navigate to the OctoPrint terminal tab and run the PROBE_ACCURACY command.

This command will run the probe ten times and produce output similar to the following:

Ideally the tool will report an identical maximum and minimum value. (That is, ideally the probe obtains an identical result on all ten probes.) However, it's normal for the minimum and maximum values to differ by one Z "step distance" or up to 5 microns (.005mm). A "step distance" is rotation_distance/(full_steps_per_rotation*microsteps) . The distance between the minimum and the maximum value is called the range. So, in the above example, since the printer uses a Z step distance of .0125, a range of 0.012500 would be considered normal.

If the results of the test show a range value that is greater than 25 microns (.025mm) then the probe does not have sufficient accuracy for typical bed leveling procedures. It may be possible to tune the probe speed and/or probe start height to improve the repeatability of the probe. The PROBE_ACCURACY command allows one to run tests with different parameters to see their impact - see the G-Codes document (https://www.klipper3d.org/G-Codes.html#probe_accuracy) for further details. If the probe generally obtains repeatable results but has an occasional outlier, then it may be possible to account for that by using multiple samples on each probe - read the description of the probe samples config parameters in the config reference (https://www.klipper3d.org/Config_Reference.html#probe) for more details.

If new probe speed, samples count, or other settings are needed, then update the printer.cfg file and issue a RESTART command. If so, it is a good idea to calibrate the z_offset again. If repeatable results can not be obtained then don't use the probe for bed leveling. Klipper has several manual probing tools that can be used instead - see the Bed Level document (https://www.klipper3d.org/Bed_Level.html) for further details.

## Location Bias Check

Some probes can have a systemic bias that corrupts the results of the probe at certain toolhead locations. For example, if the probe mount tilts slightly when moving along the Y axis then it could result in the probe reporting biased results at different Y positions.

This is a common issue with probes on delta printers, however it can occur on all printers.

Recv: // probe accuracy: at X:0.000 Y:0.000 Z:10.000 Recv: // and read 10 times with speed of 5 mm/s Recv: // probe at -0.003,0.005 is z=2.506948
Recv: // probe at -0.003,0.005 is z=2.519448
Recv: // probe at -0.003,0.005 is z=2.519448 Recv: // probe at -0.003,0.005 is z=2.506948 Recv: // probe at -0.003,0.005 is z=2.519448 Recv: // probe at -0.003,0.005 is z=2.519448 Recv: // probe at -0.003,0.005 is z=2.506948 Recv: // probe at -0.003,0.005 is z=2.506948
Recv: // probe at -0.003,0.005 is z=2.519448
Recv: // probe at -0.003,0.005 is z=2.506948
Recv: // probe accuracy results: maximum 2.519448, minimum 2.506948, range 0.012500, average 2.513198, median 2.513198, standard deviation 0.006250

One can check for a location bias by using the PROBE_CALIBRATE command to measuring the probe z_offset at various X and Y locations. Ideally, the probe z_offset would be a constant value at every printer location.

For delta printers, try measuring the z_offset at a position near the A tower, at a position near the B tower, and at a position near the C tower. For cartesian, corexy, and similar printers, try measuring the z_offset at positions near the four corners of the bed.

Before starting this test, first calibrate the probe X, Y, and Z offsets as described at the beginning of this document. Then home the printer and navigate to the first XY position. Follow the steps at calibrating probe Z offset to run the PROBE_CALIBRATE command, TESTZ commands, and ACCEPT command, but do not run SAVE_CONFIG . Note the reported z_offset found. Then navigate to the other XY positions, repeat these PROBE_CALIBRATE steps, and note the reported z_offset.

If the difference between the minimum reported z_offset and the maximum reported z_offset is greater than 25 microns (.025mm) then the probe is not suitable for typical bed leveling procedures. See the Bed Level document (https://www.klipper3d.org/Bed_Level.html) for manual probe alternatives.

## Temperature Bias

Many probes have a systemic bias when probing at different temperatures. For example, the probe may consistently trigger at a lower height when the probe is at a higher temperature.

It is recommended to run the bed leveling tools at a consistent temperature to account for this bias. For example, either always run the tools when the printer is at room temperature, or always run the tools after the printer has obtained a consistent print temperature. In either case, it is a good idea to wait several minutes after the desired temperature is reached, so that the printer apparatus is consistently at the desired temperature.

To check for a temperature bias, start with the printer at room temperature and then home the printer, move the head to a position near the center of the bed, and run the PROBE_ACCURACY command. Note the results. Then, without homing or disabling the stepper motors, heat the printer nozzle and bed to printing temperature, and run the PROBE_ACCURACY command again. Ideally, the command will report identical results. As above, if the probe does have a temperature bias then be careful to always use the probe at a consistent temperature.

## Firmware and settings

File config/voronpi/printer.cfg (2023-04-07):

# This file contains common pin mappings for the BigTreeTech Octopus V1.
# To use this config, the firmware should be compiled for the STM32F446 with a "32KiB bootloader"
# Enable "extra low-level configuration options" and select the "12MHz crystal" as clock reference

# after running "make", copy the generated "klipper/out/klipper.bin" file to a
# file named "firmware.bin" on an SD card and then restart the OctoPus with that SD card.

# See docs/Config_Reference.md for a description of parameters.

## Voron Design VORON2 250/300/350mm BigTreeTech OctoPus V1 TMC2209 UART config

## *** THINGS TO CHANGE/CHECK: ***
## MCU paths                            [mcu] section
## Thermistor types                     [extruder] and [heater_bed] sections - See https://www.klipper3d.org/Config_Reference.html#common-thermistors for common thermistor types
## Z Endstop Switch location            [safe_z_home] section
## Homing end position                  [gcode_macro G32] section
## Z Endstop Switch  offset for Z0      [stepper_z] section
## Probe points                         [quad_gantry_level] section
## Min & Max gantry corner postions     [quad_gantry_level] section
## PID tune                             [extruder] and [heater_bed] sections
## Probe pin                            [probe] section
## Fine tune E steps                    [extruder] section

[mcu]
##  Obtain definition by "ls -l /dev/serial/by-id/" then unplug to verify
##--------------------------------------------------------------------
serial: /dev/serial/by-id/usb-Klipper_stm32f446xx_3A004A000651303431333234-if00
restart_method: command
##--------------------------------------------------------------------

[include mainsail.cfg]

#[include macros_calibrate.cfg]

# Enable object exclusion
[exclude_object]

# Enable arcs support
[gcode_arcs]
resolution: 0.1

[printer]
kinematics: corexy
max_velocity: 300  
max_accel: 5000
max_accel_to_decel: 5000
#max_accel: 6200
#max_accel_to_decel: 6200
max_z_velocity: 100
max_z_accel: 1000
square_corner_velocity: 5.0

#####################################################################
#   X/Y Stepper Settings
#####################################################################

##  B Stepper - Left
##  Connected to MOTOR_0
##  Endstop connected to DIAG_0
[stepper_x]
step_pin: PF13
dir_pin: PF12
enable_pin: !PF14
rotation_distance: 40
microsteps: 32
full_steps_per_rotation:200  #set to 400 for 0.9 degree stepper
endstop_pin: PG6
position_min: 0
##--------------------------------------------------------------------

##  Uncomment below for 250mm build
#position_endstop: 250
#position_max: 250

##  Uncomment for 300mm build
position_endstop: 300
position_max: 300

##  Uncomment for 350mm build
#position_endstop: 350
#position_max: 350

##--------------------------------------------------------------------
homing_speed: 50   #Max 100
homing_retract_dist: 5
homing_positive_dir: true

##  Make sure to update below for your relevant driver (2208 or 2209)
[tmc2209 stepper_x]
uart_pin: PC4
interpolate: false
run_current: 0.8
sense_resistor: 0.110
stealthchop_threshold: 0

##  A Stepper - Right
##  Connected to MOTOR_1
##  Endstop connected to DIAG_1
[stepper_y]
step_pin: PG0
dir_pin: PG1
enable_pin: !PF15
rotation_distance: 40
microsteps: 32
full_steps_per_rotation:200  #set to 400 for 0.9 degree stepper
endstop_pin: PG9
position_min: 0
##--------------------------------------------------------------------

##  Uncomment for 250mm build
#position_endstop: 250
#position_max: 250

##  Uncomment for 300mm build
position_endstop: 305
position_max: 305

##  Uncomment for 350mm build
#position_endstop: 350
#position_max: 350

##--------------------------------------------------------------------
homing_speed: 50  #Max 100
homing_retract_dist: 5
homing_positive_dir: true

##  Make sure to update below for your relevant driver (2208 or 2209)
[tmc2209 stepper_y]
uart_pin: PD11
interpolate: false
run_current: 0.8
sense_resistor: 0.110
stealthchop_threshold: 0
 
#####################################################################
#   Z Stepper Settings
#####################################################################

## Z0 Stepper - Front Left
##  Connected to MOTOR_2
##  Endstop connected to DIAG_2
[stepper_z]
step_pin: PF11
dir_pin: PG3
enable_pin: !PG5
rotation_distance: 40
gear_ratio: 80:16
microsteps: 32
#endstop_pin: PG10
endstop_pin: probe:z_virtual_endstop
##  Z-position of nozzle (in mm) to z-endstop trigger point relative to print surface (Z0)
##  (+) value = endstop above Z0, (-) value = endstop below
##  Increasing position_endstop brings nozzle closer to the bed
##  After you run Z_ENDSTOP_CALIBRATE, position_endstop will be stored at the very end of your config
#position_endstop: -0.5
##--------------------------------------------------------------------

##  Uncomment below for 250mm build
#position_max: 210

##  Uncomment below for 300mm build
position_max: 270

##  Uncomment below for 350mm build
#position_max: 310

##--------------------------------------------------------------------
position_min: -5
homing_speed: 8
second_homing_speed: 3
homing_retract_dist: 3

##  Make sure to update below for your relevant driver (2208 or 2209)
[tmc2209 stepper_z]
uart_pin: PC6
interpolate: false
run_current: 0.8
sense_resistor: 0.110
stealthchop_threshold: 0

##  Z1 Stepper - Rear Left
##  Connected to MOTOR_3
[stepper_z1]
step_pin: PG4
dir_pin: !PC1
enable_pin: !PA0
rotation_distance: 40
gear_ratio: 80:16
microsteps: 32

##  Make sure to update below for your relevant driver (2208 or 2209)
[tmc2209 stepper_z1]
uart_pin: PC7
interpolate: false
run_current: 0.8
sense_resistor: 0.110
stealthchop_threshold: 0

##  Z2 Stepper - Rear Right
##  Connected to MOTOR_4
[stepper_z2]
step_pin: PF9
dir_pin: PF10
enable_pin: !PG2
rotation_distance: 40
gear_ratio: 80:16
microsteps: 32

##  Make sure to update below for your relevant driver (2208 or 2209)
[tmc2209 stepper_z2]
uart_pin: PF2
interpolate: false
run_current: 0.8
sense_resistor: 0.110
stealthchop_threshold: 0

##  Z3 Stepper - Front Right
##  Connected to MOTOR_5
[stepper_z3]
step_pin: PC13
dir_pin: !PF0
enable_pin: !PF1
rotation_distance: 40
gear_ratio: 80:16
microsteps: 32

##  Make sure to update below for your relevant driver (2208 or 2209)
[tmc2209 stepper_z3]
uart_pin: PE4
interpolate: false
run_current: 0.8
sense_resistor: 0.110
stealthchop_threshold: 0


#####################################################################
#   Extruder
#####################################################################

##  Connected to MOTOR_6
##  Heater - HE0
##  Thermistor - T0
[extruder]
step_pin: PE2
dir_pin: PE3
enable_pin: !PD4
##  Update value below when you perform extruder calibration
##  If you ask for 100mm of filament, but in reality it is 98mm:
##  rotation_distance = <previous_rotation_distance> * <actual_extrude_distance> / 100
##  22.6789511 is a good starting point
rotation_distance: 22.6789511   #Bondtech 5mm Drive Gears
##  Update Gear Ratio depending on your Extruder Type
##  Use 50:17 for Afterburner/Clockwork (BMG Gear Ratio)
##  Use 80:20 for M4, M3.1
gear_ratio: 50:17               #BMG Gear Ratio
microsteps: 32
full_steps_per_rotation: 200    #200 for 1.8 degree, 400 for 0.9 degree
nozzle_diameter: 0.400
filament_diameter: 1.75
heater_pin: PA2
## Check what thermistor type you have. See https://www.klipper3d.org/Config_Reference.html#common-thermistors for common thermistor types.
## Use "Generic 3950" for NTC 100k 3950 thermistors
# sensor_type: Generic 3950
sensor_type: ATC Semitec 104NT-4-R025H42G
sensor_pin: PF4
min_temp: 10
max_temp: 270
max_power: 1.0
min_extrude_temp: 170
#control = pid
#pid_kp = 26.213
#pid_ki = 1.304
#pid_kd = 131.721
##  Try to keep pressure_advance below 1.0
pressure_advance: 0.04 # revo hotend
#pressure_advance: 0.03 # orginal V6 hotend
##  Default is 0.040, leave stock
#pressure_advance_smooth_time: 0.040

##  E0 on MOTOR6
##  Make sure to update below for your relevant driver (2208 or 2209)
[tmc2209 extruder]
uart_pin: PE1
interpolate: false
run_current: 0.3
hold_current: 0.2
sense_resistor: 0.110
stealthchop_threshold: 0


#####################################################################
#   Bed Heater
#####################################################################
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

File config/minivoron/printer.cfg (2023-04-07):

[include fly_macros.cfg]

########################################
# Motherboard model
# Please modify it based on your motherboard model
########################################
#[include boards/FLY_GEMINI_V1.cfg]
#[include boards/FLY_GEMINI_V1.1.cfg]
[include boards/FLY_GEMINI_V3.cfg]

# Enable object exclusion
[exclude_object]

# Enable arcs support
[gcode_arcs]
resolution: 0.1

[mcu]
serial: /dev/Gemini_MCU

[mcu host]
serial: /tmp/klipper_host_mcu

[virtual_sdcard]
path: ~/gcode_files

[printer]
kinematics: corexy
max_velocity: 190
max_accel: 2000
max_z_velocity: 15
max_z_accel: 100

########################################
# Temp
########################################
[temperature_sensor FLY-Gemini]
sensor_type: temperature_host

[temperature_sensor FLY-MCU]
sensor_type: temperature_mcu

########################################
# Drives
########################################
[stepper_x]
step_pin: X_STEP
dir_pin: X_DIR
enable_pin: !X_EN
microsteps: 32
rotation_distance: 40
endstop_pin: X_STOP
position_endstop: 120
position_max: 120
homing_speed: 40
step_pulse_duration: 0.000004

[stepper_y]
step_pin: Y_STEP
dir_pin: Y_DIR
enable_pin: !Y_EN
microsteps: 32
rotation_distance: 40
endstop_pin: Y_STOP
position_endstop: 119
position_max: 119
homing_speed: 40
step_pulse_duration: 0.000004

[stepper_z]
step_pin: Z_STEP
dir_pin: !Z_DIR
enable_pin: !Z_EN
microsteps: 32
rotation_distance: 8
endstop_pin: Z_STOP
#position_endstop: 0.5
position_max: 118
position_min: -0.1

[extruder]
step_pin: E_STEP
dir_pin: !E_DIR
enable_pin: !E_EN
microsteps: 32
rotation_distance: 23
gear_ratio: 50:10   
nozzle_diameter: 0.400
filament_diameter: 1.750
heater_pin: HEAT
sensor_pin: HEAT_TEMP
sensor_type: ATC Semitec 104NT-4-R025H42G
min_temp: 0
max_temp: 270
max_power: 0.2
min_extrude_temp: 170
##  Try to keep pressure_advance below 1.0
pressure_advance: 0.02 # revo hotend
#control: pid
#pid_Kp: 22.2
#pid_Ki: 1.08
#pid_Kd: 114

########################################
# BED
########################################
[heater_bed]
heater_pin: BED_OUT
sensor_pin: BED_TEMP
sensor_type: ATC Semitec 104GT-2
min_temp: 0
max_temp: 100
max_power: 0.5
control: pid
pid_kp: 33.590
pid_ki: 0.573
pid_kd: 492.510

########################################
# FANs
########################################
[multi_pin my_fan]
pins: FAN0, FAN1

[fan]
pin = multi_pin:my_fan
kick_start_time: 0.5

#[heater_fan hotend_fan]
#pin: FAN2
#max_power: 1.0
#kick_start_time: 0.5
#heater: extruder
#heater_temp: 30.0

#[fan]
#pin: FAN0

#[fan_generic fan1]
#pin: FAN1

########################################
# TMC2208 configuration./2209/2225
########################################
[tmc2209 stepper_x]
uart_pin: X_CS
run_current: 0.800
interpolate: False
stealthchop_threshold:200

[tmc2209 stepper_y]
uart_pin: Y_CS
run_current: 0.800
interpolate: False
stealthchop_threshold:200

[tmc2209 stepper_z]
uart_pin: Z_CS
run_current: 0.4500
interpolate: False

[tmc2209 extruder]
uart_pin: E_CS
run_current: 0.4500
interpolate: False

######################################
# Bed Screws for bed leveling
######################################
[bed_screws]
screw1: 59.5, 3.5
screw2: 4.5, 112.5
screw3: 114.5, 112.5
probe_height: 1

######################################
# Macros
######################################
#[gcode_macro TEST]
#gcode:
#    {% set safe_z = -printer.gcode_move.homing_origin.z|float %}
#    G0 Z{safe_z}

[gcode_macro BED_LEVEL]
gcode:
    G28
    BED_SCREWS_ADJUST

[gcode_macro BED_ACCEPT]
gcode:
    ACCEPT

[gcode_macro BED_ADJUSTED]
gcode:
    ADJUSTED

[gcode_macro FRONT]
gcode:
    G0 X60 Y10 F8000

[gcode_macro PRINT_START]
#   Use PRINT_START for the slicer starting script - please customize for your slicer of choice
gcode:
    {% set zero_z = -printer.gcode_move.homing_origin.z|float %}
    G28
    G0 Z2 F1000
    FRONT
    G0 Z{zero_z} F1000
    G0 F3000
    G90                            ; absolute positioning

#    G90
#    M107
#    M82
#    G28
#    G1 Z20 F3000
#    G92 E0
#    G1 X110 Y0.5 F2000
#    G1 Z0.28 F400
#    G1 X30 Y0.5 E18 F1000
#    G1 Z0.5 F200
#    G92 E0

    #G28                            ; home all axes
    #G1 Z20 F3000                   ; move nozzle away from bed
    
[gcode_macro PRINT_END]
#   Use PRINT_END for the slicer ending script - please customize for your slicer of choice
gcode:
    M400                           ; wait for buffer to clear
    G92 E0                         ; zero the extruder
    G1 E-1.0 F3600                 ; retract filament
    G91                            ; relative positioning

    #   Get Boundaries
    {% set max_x = printer.configfile.config["stepper_x"]["position_max"]|float %}
    {% set max_y = printer.configfile.config["stepper_y"]["position_max"]|float %}
    {% set max_z = printer.configfile.config["stepper_z"]["position_max"]|float %}

    #   Check end position to determine safe direction to move
    {% if printer.toolhead.position.x < (max_x - 20) %}
        {% set x_safe = 20.0 %}
    {% else %}
        {% set x_safe = -20.0 %}
    {% endif %}

    {% if printer.toolhead.position.y < (max_y - 20) %}
        {% set y_safe = 20.0 %}
    {% else %}
        {% set y_safe = -20.0 %}
    {% endif %}

    {% if printer.toolhead.position.z < (max_z - 2) %}
        {% set z_safe = 2.0 %}
    {% else %}
        {% set z_safe = max_z - printer.toolhead.position.z %}
    {% endif %}

    G0 Z{z_safe} F3600             ; move nozzle up
    G0 X{x_safe} Y{y_safe} F20000  ; move nozzle to remove stringing
    TURN_OFF_HEATERS
    M107                           ; turn off fan
    G90                            ; absolute positioning
    G0 X60 Y{max_y} F3600          ; park nozzle at rear
    SET_SKEW CLEAR=1

########################################
# BLTouch
########################################
#[bltouch]
#sensor_pin: ^PROBE
#control_pin: SERVO
#pin_move_time: 0.680
#x_offset: 0.0
#y_offset: 2.3
#z_offset: 2.2
#speed: 70

#[safe_z_home]
#home_xy_position: 105,105

########################################
# Mini 12864 LCD
########################################
#[display]
#lcd_type: uc1701
#cs_pin: EXP1_3
#a0_pin: EXP1_4
#rst_pin: EXP1_5
#contrast: 63
#encoder_pins: ^EXP2_5, ^!EXP2_3
#click_pin: ^!EXP1_2
##spi_bus: spi1

#####适用于FLY Mini12864
#[neopixel fly_mini12864]
#pin: EXP1_6
#chain_count: 3
#initial_RED: 0.1
#initial_GREEN: 0.5
#initial_BLUE: 0.0
#color_order: RGB

#*# <---------------------- SAVE_CONFIG ---------------------->
#*# DO NOT EDIT THIS BLOCK OR BELOW. The contents are auto-generated.
#*#
#*# [extruder]
#*# control = pid
#*# pid_kp = 8.672
#*# pid_ki = 1.314
#*# pid_kd = 14.308
#*#
#*# [stepper_z]
#*# position_endstop = 0.000

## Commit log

2022-12-06 Added some images and models
    [V2.4585-NoLogo.stl, V2.4585.stl, printhead_rear_revovoron.stl]
2022-12-06 Added some config
    [macros_calibrate.cfg, mainsail.cfg, printer.cfg]
2022-12-06 Added the 40x10 model
    [40x10-solid.stl]
2022-12-11 Add pressure advance pdf
2022-12-11 Add bed mesh pdf
2022-12-14 Added fiber models
    [fiber-rpi4.stl, fiber-skirt.stl]
2023-01-01 Update for tap
    [mainsail.cfg, printer.cfg]
2023-01-01 Added modded cover for AB
    [ab-cover-cutout.stl]
2023-01-01 Addded Probe calibration pdf
2023-01-01 Saved input shaper result
    [printer.cfg]
2023-01-07 Tweaked some default positions, tap speed
    [mainsail.cfg, printer.cfg]
2023-01-08 Update printer.cfg, removed G32. Probe samples 3->1
    [printer.cfg]
2023-03-19 Added my V0.1
    [FLY_GEMINI_V3.cfg, V0.2486-NoLogo.stl, V0.2486.stl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]
2023-03-19 Add minivoron confs
    [FLY_GEMINI_V1.1.cfg, FLY_GEMINI_V1.cfg, FLY_GEMINI_V2.cfg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]
2023-04-07 Update April 2023
    [printer.cfg]
